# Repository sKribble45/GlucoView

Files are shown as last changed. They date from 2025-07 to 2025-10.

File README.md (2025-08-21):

# GlucoView
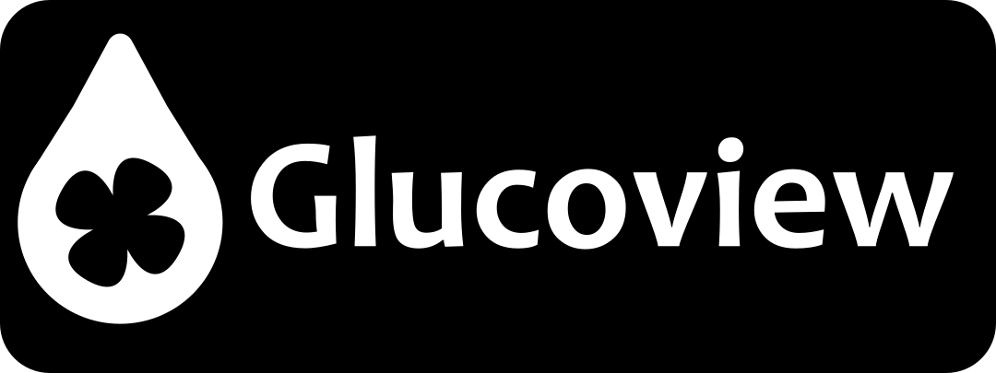
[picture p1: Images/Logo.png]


GlucoView is a low power, wall mounted E-paper display made for type one diabetics, used for checking blood sugar levels at a glance.

### <b style="color:red">WARNING: I am not a medical profesional, do not use this device for treatment decisions. Use ar your own risk.</b>

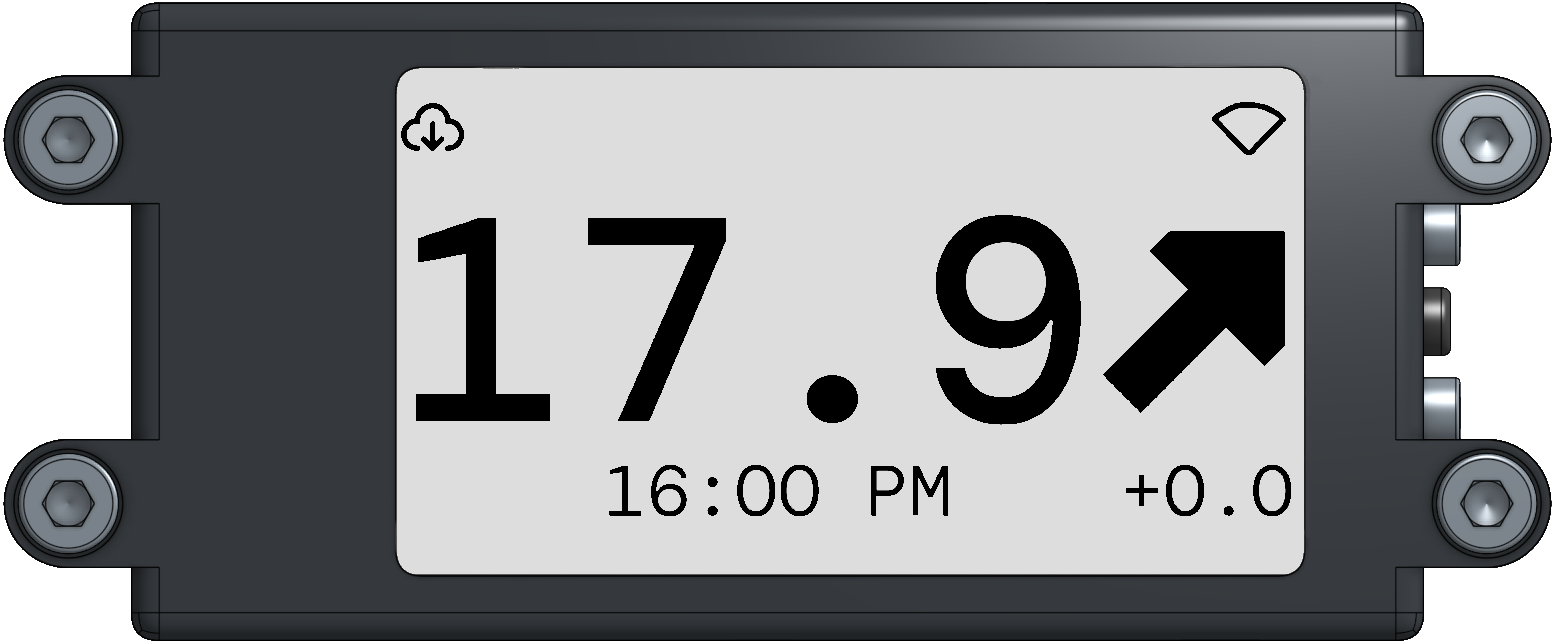
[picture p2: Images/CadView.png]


## Features:
- Uses a web UI and QR codes to make it simple and easy to configure using a smart device.
- Has options for dexcom share or nightscout data sources.
- Displays delta of glucose level on screen to make it easier to judge the rate of change.
- Uses an epaper screen and deep sleep which allows it to be extremely low power.
- Uses partial updates on the screen so glucose updates display extremely quick.
- Has OTA (Over the air) updates so you never have to manualy update.
- Mg/dl or Mmol/l option.

## Future plans
- List wifi networks rather than enter ssid manualy.
- Multiple Ui options including a graph.
- Battery powered version.
- Custom PCB.

## Configuration:
It uses a web ui to configure the wifi and dexcom credentials aswell as other settings. It is accesed by pressing the pairing button on the side of the device and scanning 2 Qr codes (One for the access point and one for the web page).

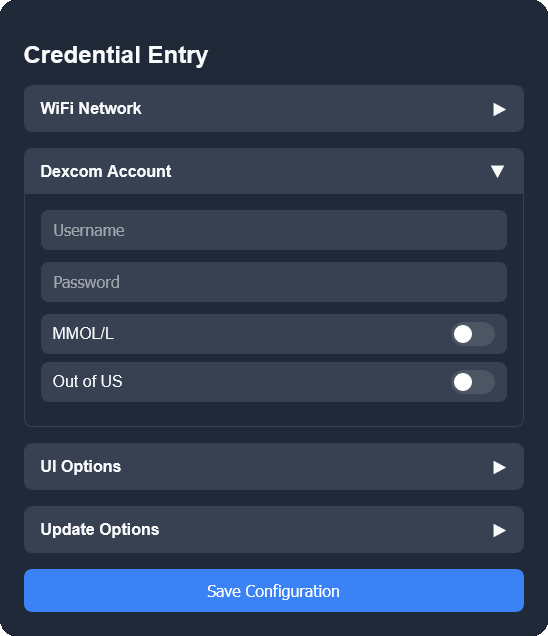
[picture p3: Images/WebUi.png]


# Build Your Own

## Cad Models:
Build Status (https://cad.onshape.com/documents/657beeeeb3e29ae5b1578280/w/7df4418e981bbd9b2a29f8d4/e/0c90e781795b9ee73095e2fe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)

[Stl Files](./Models)

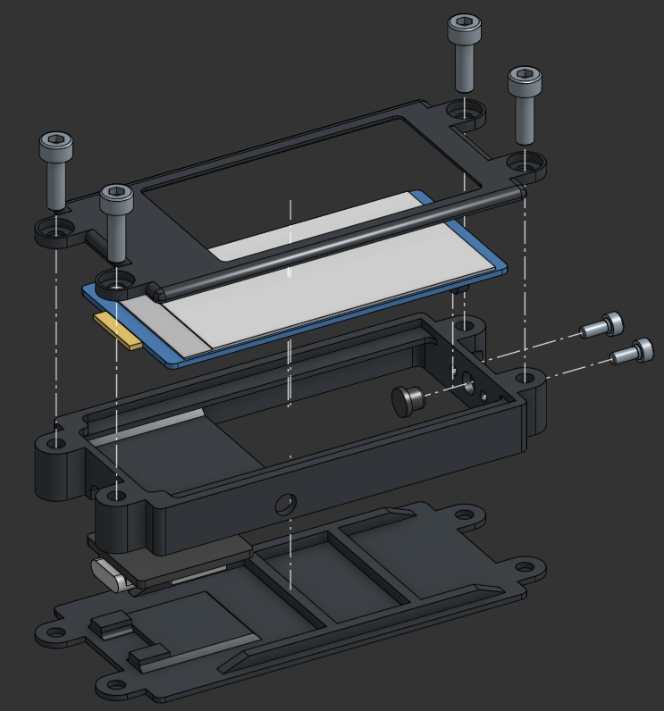
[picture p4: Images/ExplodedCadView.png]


## Parts:
- Esp32 S3 microcontroler from [Seeed Studio](https://www.seeedstudio.com/Seeed-Studio-XIAO-ESP32S3-Plus-p-6361.html) (Specificialy the Seed Studio XIAO ESP32-S3 Plus)
- 2.13 inch E-Paper display from [Waveshare](https://www.waveshare.com/pico-epaper-2.13.htm) (headers need to be de-soldered)
- [Push button](https://www.amazon.co.uk/B0BQ3CKVMT) (6mm x 6mm x 4.5mm)
- [Wire](https://shop.pimoroni.com/products/wire-spool?variant=40461209162) (Any wire will do as long as it is decently thin)
- [M3 x 14mm Bolts](https://www.amazon.co.uk/dp/B01FL898DU)
- M2 x 10mm & M2 x 6mm Bolts & M2 Nuts([M2 screw set](https://www.amazon.co.uk/Screws-Washers-Assortment-Socket-Printer/dp/B0CPHM3RC1))

## Tools required:
- Soldering iron, I recommend the [Pine 64 Pinecil](https://pine64.com/product/pinecil-smart-mini-portable-soldering-iron/).
- [Solder](https://www.amazon.co.uk/B08YRJJCV5) (Any will do, though i would reccomend lead free)
- [Wire cutters](https://shop.pimoroni.com/products/engineer-plastic-nippers?variant=41686138159187) (Any will do, these are just nice high quality ones)
- [Pliers](https://shop.pimoroni.com/products/miniature-needle-nose-pliers?variant=41151537250387) (Again any will do, these are just high quality)
- Alen keys / Screwdriver with alen bits.
- 3d printer or a service like [PCBway](https://www.pcbway.com/) or [jlcPCB](https://jlcpcb.com/)

## Pinout:
| Xiao ESP32 S3  | Device |
| --- | --- |
| D8 | EPD CLK |
| D10 | EPD DIN |
| D0 | EPD CS |
| D3 | EPD RST |
| D2 | EPD DC |
| D4 | EPD BUSY |
| D5 | BUTTON |

## Wiring Diagram:
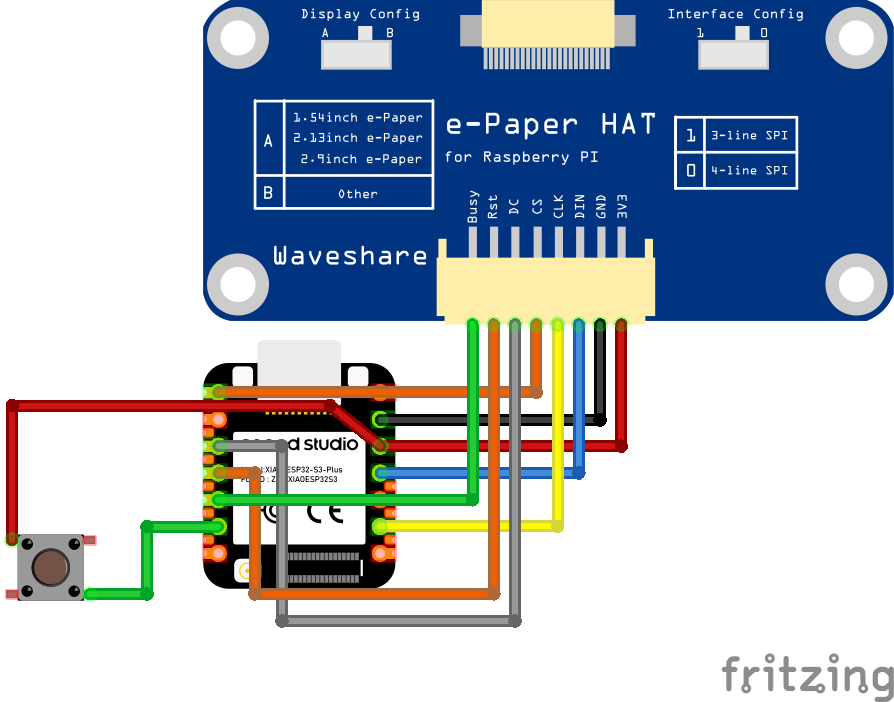
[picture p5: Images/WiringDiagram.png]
Wiring Diagram


### Guide comming soon :)

## Font License

This project uses a modified version of the DM Mono font, originally by Colophon Foundry.

The font has been renamed and modified to comply with the [SIL Open Font License 1.1](https://scripts.sil.org/OFL).  
See [FONT_LICENSES](./FONT_LICENSE.md) for full details.

## Credits:
- QR Code Libary by [Richard Moore](https://github.com/ricmoo/QRCode?tab=readme-ov-file)

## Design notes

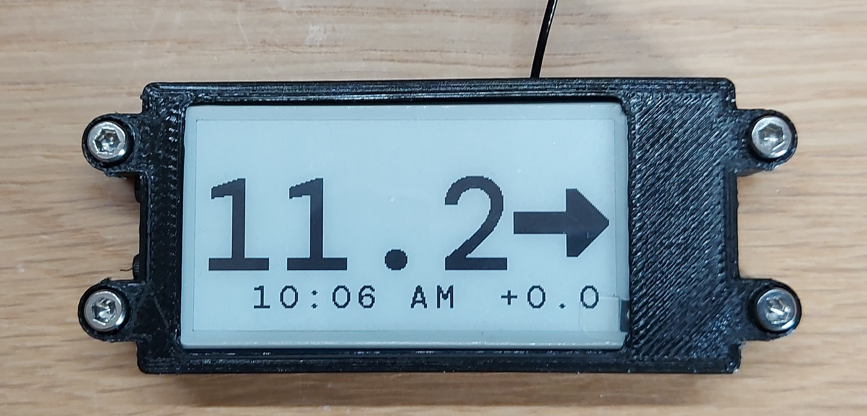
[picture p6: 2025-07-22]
Images/MainScreen.jpg

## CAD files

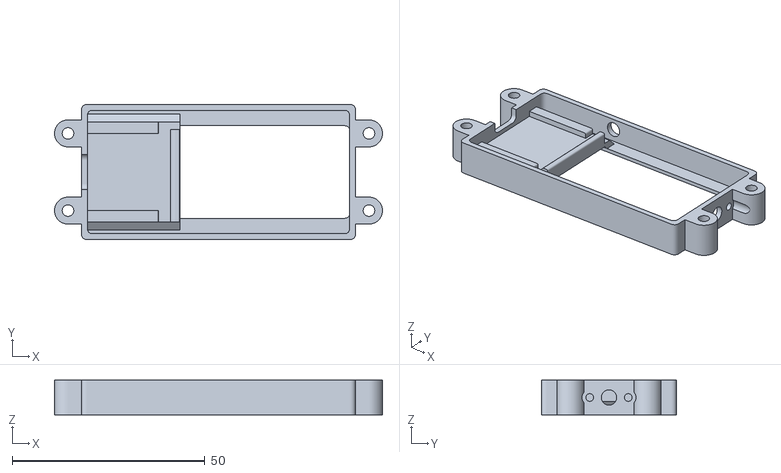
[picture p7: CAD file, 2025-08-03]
Models/Main Body.stl
85.0 x 35.0 x 9.00

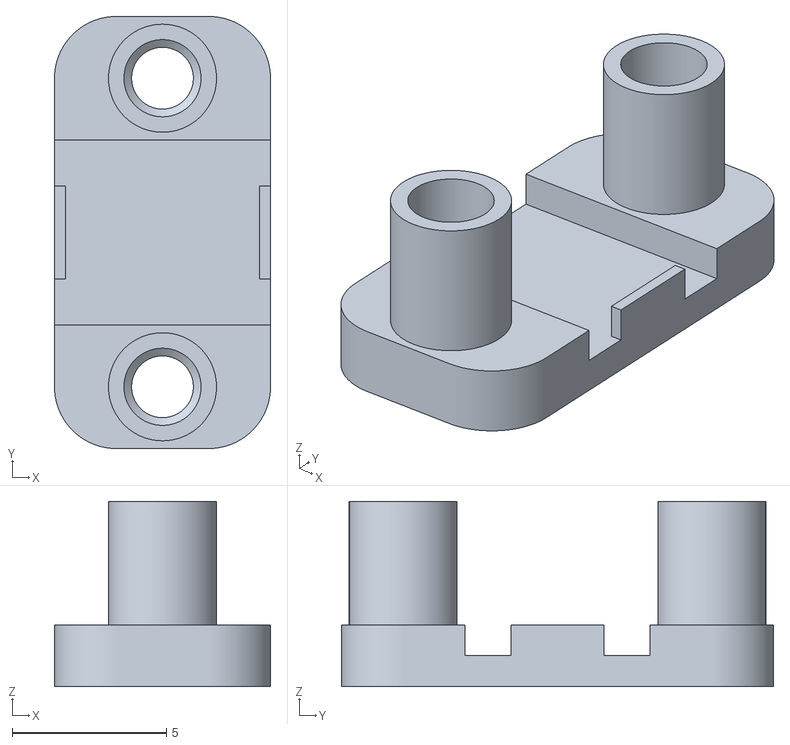
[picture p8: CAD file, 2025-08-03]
Models/Button Bracket.stl
7.00 x 14.0 x 6.00

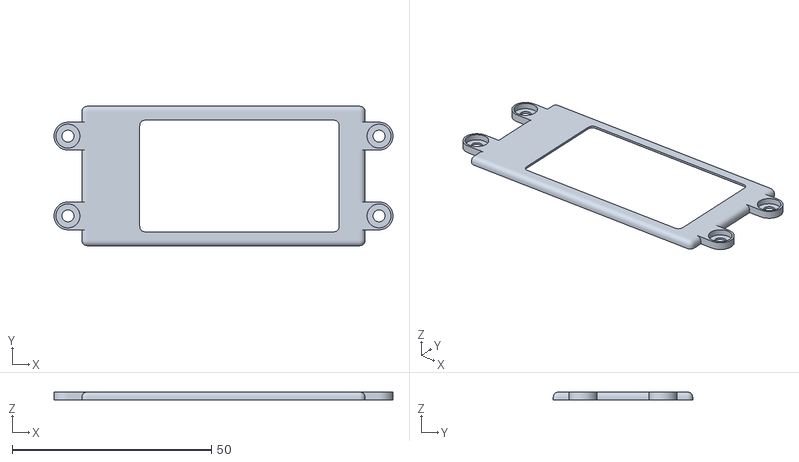
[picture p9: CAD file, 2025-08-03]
Models/Screen Besel.stl
85.0 x 35.0 x 2.00

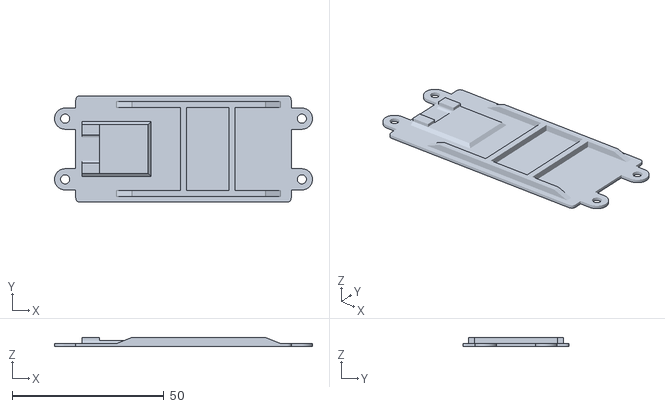
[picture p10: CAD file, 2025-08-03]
Models/Back Plait.stl
85.0 x 35.0 x 3.00

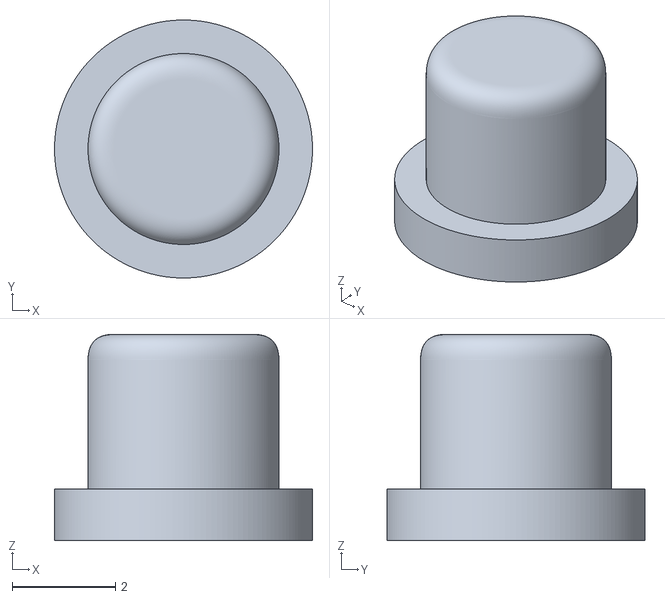
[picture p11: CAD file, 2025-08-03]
Models/Button.stl
5.00 x 5.00 x 4.00

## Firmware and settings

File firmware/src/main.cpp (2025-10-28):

#include <WiFi.h>
#include <Arduino.h>
#include <WiFiUdp.h>
#include <stdlib.h>
#include "UI.h"
#include "config/config_manager.h"
#include "wifi_manager.h"
#include "driver/rtc_io.h"
#include <nvs_flash.h>
#include "images/arrows.h"
#include "glucose_screen.h"
#include "update_manager.h"
#include "epoch_time.h"
#include "sleep.h"
#include "glucose/bg_datasource.h"
#include "config/config_ap.h"
using namespace std;

esp_sleep_wakeup_cause_t wakeup_reason;
RTC_DATA_ATTR GlucoseReading prevGl;

time_t rtcTime;

// Sleep times.
const int NO_TIME_SLEEP = 5;
const int NO_DATA_SLEEP = 5*60;
const int RETRY_NO_DATA_SLEEP = 15;
const int RETRY_TIMOUT_WIFI_SLEEP = 10;
const int WIFI_TIMEOUT_SLEEP = 30;
const int NO_WIFI_SLEEP = 5*60;
const int RETRY_NO_WIFI_SLEEP = 20;
const int DS_ERROR_SLEEP = 20;

const int SLEEP_TIME_DELAY = 4;

enum State{
    STATE_NORMAL,
    STATE_NO_DATA,
    STATE_NO_DATA_RETRY,
    STATE_NO_WIFI,
    STATE_WIFI_TIMEOUT,
    STATE_INCORRECT_WIFI,
    STATE_DS_ERROR
};

RTC_DATA_ATTR enum State state = STATE_NORMAL;

void RelTimestampSleep(int timeUntilNewReading){
    // Work out how long to sleep.
    int sleepTimeRemainder = timeUntilNewReading - (round(timeUntilNewReading/60)*60);
    if (sleepTimeRemainder == timeUntilNewReading){
        Sleep(sleepTimeRemainder + SLEEP_TIME_DELAY);
    }
    
    if (sleepTimeRemainder > 0){
        Sleep(sleepTimeRemainder);
    }
    else{
        Sleep(60);
    }
}

void NoData(unsigned long currentTime, Config config){
    if (state == STATE_NO_DATA_RETRY || state == STATE_NO_DATA){
        state = STATE_NO_DATA;
        Serial.println("No Data");
        DisplayError("No Data", true);

        int timeSniceLastReading = currentTime - prevGl.timestamp;
        int timeUntilNextReadingCheck = (5*60) - timeSniceLastReading - floor((timeSniceLastReading/60)/5)*5*60;
        if (!GetBooleanValue("rel-timestamp", config)){
            Sleep(timeUntilNextReadingCheck + SLEEP_TIME_DELAY);
        }
        else{
            RelTimestampSleep(timeUntilNextReadingCheck);
        }
    }
    else{
        state = STATE_NO_DATA_RETRY;
        Serial.println("No new reading yet.");
        Sleep(RETRY_NO_DATA_SLEEP);
    }
}

bool ShouldUpdateBg(unsigned long rtcTime){
    bool updateBg;
    int minsSinceLastReading = round((rtcTime - prevGl.timestamp)/60);
    updateBg = (
        // If it is 5m after the last reading.
        (state == STATE_NORMAL && (rtcTime - prevGl.timestamp > 5*60 - SLEEP_TIME_DELAY)) || 
        // Check if its a multiple of 5 if the state is No Data.
        (state == STATE_NO_DATA && minsSinceLastReading%5 == 0) ||
        (state == STATE_NO_DATA_RETRY)
    );
    return updateBg;
}

void UpdateDisplayGlucose(Config config){
    // Get the current epoch time.
    unsigned long currentTime = rtcTime;

    // Get the blood glucose reading from dexcom.
    GlucoseReading gl = prevGl;
    currentTime = GetEpoch();
    Serial.print("Epoch: ");
    Serial.println(currentTime);
    // Check if ntp time worked
    if (currentTime == 0){
        // If the ntp time dosnt work use inbuilt rtc if it has been set
        if (rtcTime > 10){
            Serial.println("Timeclient not updating, using built in rtc time.");
            currentTime = rtcTime;
        }
        else{
            // Reset as the rtc has not been set to the time via wifi.
            Serial.println("No previous time data.");
            Sleep(NO_TIME_SLEEP);
        }
    }
    if (GetGl()){
        gl = GlNow();
    }
    else{
        Serial.println("DS Error");
        DisplayError("DS Error", true);
        Sleep(DS_ERROR_SLEEP);
    }
    
    PrintGlucose(gl);
    prevGl = gl;
    
    // Update checking
    bool updateNeeded = CheckForUpdate();
    Serial.print("Update Needed: ");
    Serial.println(updateNeeded);
    if (GetBooleanValue("update-check", config)){
        UpdateGsNeedUpdate(updateNeeded);
    }
    if (GetBooleanValue("auto-update", config) && updateNeeded){
        OtaUpdate();
    }

    // No longer need wifi so turn it off to save some power.
    WiFi.disconnect(true);
    WiFi.mode(WIFI_OFF);

    // SLEEP!
    
    int timeUntilNewReading = (5 * 60) - (currentTime - gl.timestamp);

    // sleep for the next reading.
    if(timeUntilNewReading < 0){
        gl.minsSinceReading = round((currentTime - gl.timestamp) / 60);
        DisplayGlucose(gl);

        NoData(currentTime, config);
    }
    else {
        PrintGlucose(gl);
        DisplayGlucose(gl);
        
        state = STATE_NORMAL;
        if (GetBooleanValue("rel-timestamp", config)){
            RelTimestampSleep(timeUntilNewReading);
        }
        else{
            Sleep(timeUntilNewReading + SLEEP_TIME_DELAY);
        }
    }
}

void UpdateDisplay(){
    prevGl.minsSinceReading = round((rtcTime - prevGl.timestamp) / 60);
    
    PrintGlucose(prevGl);
    if (state == STATE_NO_DATA){
        DisplayError("No Data", true, prevGl);
    }
    else{
        DisplayGlucose(prevGl);
    }
    
    int timeUntilNewReading = (5 * 60) - (rtcTime - prevGl.timestamp);

    RelTimestampSleep(timeUntilNewReading);
}

void OnStart(Config config) {
    String wifiSsid = GetStringValue("wifi-ssid", config);
    String wifiPassword = GetStringValue("wifi-password", config);
    #if DEBUG
        Serial.print("ssid: ");
        Serial.print(wifiSsid);
        Serial.print(" , password: ");
        Serial.println(wifiPassword);
    #endif
    
    time(&rtcTime);
    Serial.print("RTC time: ");
    Serial.println(rtcTime);

    if (ShouldUpdateBg(rtcTime) || prevGl.bg == 0.0 || rtcTime <= 10){
        int networkConnectionCode = ConnectToNetwork(wifiSsid, wifiPassword);
        if (networkConnectionCode == 0){
            UpdateGsSignalStrength(GetWifiSignalStrength());
            UpdateDisplayGlucose(config);
        }
        else{
            UpdateGsSignalStrength(0);
            bool savedNetworkExists = SavedNetworkExists(wifiSsid);
            if (savedNetworkExists){
                if (networkConnectionCode == 6){
                    Serial.println("Failed to connect to wifi network (Incorrect Password) :(");
                    if (state != STATE_INCORRECT_WIFI){
                        state = STATE_INCORRECT_WIFI;
                        Sleep(WIFI_TIMEOUT_SLEEP);
                    }
                    else{
                        DisplayError("WiFi Fail", true);
                        Sleep(NO_WIFI_SLEEP);
                    }
                }
                else{
                    Serial.println("Failed to connect to wifi network (Timed out) :(");
                    if (state != STATE_WIFI_TIMEOUT){
                        state = STATE_WIFI_TIMEOUT;
                    }
                    Sleep(WIFI_TIMEOUT_SLEEP);
                    
                    //TODO: Handle Error
                }
            }
            else{
                Serial.println("Failed to connect to wifi network (Not found) :(");
                state = STATE_NO_WIFI;
                Sleep(NO_WIFI_SLEEP);
                //TODO: Handle Error
            }
        }
    }
    else{
        Serial.println("Updating Mins since reading.");
        UpdateDisplay();
    }
}

void StartConfiguration(Config &config){
    String ApPassword = "glucoview_"+GetSerialNumber();
    String ApSsid = "GlucoView" + GetSerialNumber();
    HostConfigAP(config, ApSsid.c_str(), ApPassword.c_str());
    SaveConfig(config);

    UiFullClear();
    UiSetupFinish();
    UiShow();
    while (!digitalRead(BUTTON_PIN)){delay(50);}
    while (digitalRead(BUTTON_PIN)){delay(50);}
    ESP.restart();
}

void setup(){
    Serial.begin(115200);
    // Get the reason it was woken from sleep.
    wakeup_reason = esp_sleep_get_wakeup_cause();
    // Pull down the button pin to ground so it can see a change when shorted to 3.3v
    pinMode(BUTTON_PIN, INPUT_PULLDOWN);
    int buttonValue = digitalRead(BUTTON_PIN);

    Serial.println("Initialise display");
    DispInit();
    Serial.println("Display initilised.");

    // If it hasnt woken up from sleep because of the button press (so not pairing) and the button is down (when it is plugged )
    if (wakeup_reason != ESP_SLEEP_WAKEUP_EXT0 && buttonValue) {UpdateMode();}

    //!! DO NOT REMOVE CODE BEFORE THIS MESSAGE UNLESS YOU KNOW WHAT YOU ARE DOING (you may need to take appart the device to bootstrap so that you can re-program if you do)

    // Delay to connect to serial port.
    #if DEBUG
        delay(2000);
    #endif

    Config config;
    LoadConfig(config);
    #if DEBUG
        PrintConfigValues(config);
    #endif
    // Load config to other components.
    UpdateUiConfig(config);
    UpdateUpdateManagerConfig(config);
    UpdateDataSourceConfig(config);

    // Setup screen when you start the device for the first time.
    if (!SerialNumberExists() || !ConfigExists(config)){
        UiSetupScreen();
        UiShow();
        while (!digitalRead(BUTTON_PIN)){delay(50);}
        RandomiseSerialNumber();
        delay(50);
        StartConfiguration(config);
    }

    // If it was woken up by the button press (or config dosnt exist) enter configuration mode.
    if (wakeup_reason == ESP_SLEEP_WAKEUP_EXT0){
        Serial.println("Entering Configuration");
        StartConfiguration(config);
        // Restart the device after configuration.
        ESP.restart();
    }

    // Run the main start code
    OnStart(config);
}


void loop(){
    // :)
}

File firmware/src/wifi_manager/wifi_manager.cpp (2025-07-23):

#include <WiFi.h>
#include <WiFiUdp.h>
#include <list>
#include "wifi_manager.h"
#include <Arduino.h>
#include <unordered_map>
using namespace std;
const int WIFI_TIMEOUT = 15;

bool SavedNetworkExists(WifiNetwork network){
    WiFi.disconnect();
    // Scan for networks.
    Serial.println("Scanning for networks...");
    int foundNetworks = WiFi.scanNetworks();
    Serial.println("Finished scanning.");
    // if there are no networks found display no wifi and sleep.
    if (foundNetworks == 0){
        Serial.println("No wifi networks found :(");
        return false;
    }

    Serial.println("Networks Found:");
    for (int scannedNetworkIndex = 0; scannedNetworkIndex < foundNetworks; scannedNetworkIndex++){
        String scanned_network_ssid = WiFi.SSID(scannedNetworkIndex); // get the ssid from the index of a network that has has been scanned
        Serial.print(" -");
        Serial.println(scanned_network_ssid);


        // if the ssid from one of the saved networks equals one of the scanned networks then 
        if (network.ssid == scanned_network_ssid){
            Serial.print("Found saved network: ");
            Serial.println(network.ssid);
            return true;
        }
        
    }
    return false;
}

WifiNetwork GetSavedNetwork(list<WifiNetwork> saved_networks){
    WiFi.disconnect();
    // Scan for networks.
    Serial.println("Scanning for networks...");
    int foundNetworks = WiFi.scanNetworks();
    Serial.println("Finished scanning.");
    // if there are no networks found display no wifi and sleep.
    if (foundNetworks == 0){
        Serial.println("No wifi networks found :(");
        return {"",""};
    }

    bool savedNetworkExists = false;
    WifiNetwork network = {"", ""};


    Serial.println("Networks Found:");
    for (int scannedNetworkIndex = 0; scannedNetworkIndex < foundNetworks; scannedNetworkIndex++){
        String scanned_network_ssid = WiFi.SSID(scannedNetworkIndex); // get the ssid from the index of a network that has has been scanned
        
        Serial.print(" -");
        Serial.print(scanned_network_ssid);
        Serial.print(" ");
        Serial.println(WiFi.RSSI(scannedNetworkIndex));

        for (WifiNetwork saved_network : saved_networks){
            // nicer variable names cuz i feel like it.
            String ssid = saved_network.ssid;
            String pass = saved_network.password;
            // if the ssid from one of the saved networks equals one of the scanned networks then return it.
            if (ssid == scanned_network_ssid){
                savedNetworkExists = true;
                network.ssid = scanned_network_ssid;
                network.password = pass;
                break;
            }
        }
        if (savedNetworkExists){
            Serial.print("Found saved network: ");
            Serial.println(network.ssid);
            break;
        }
    }
    WiFi.scanDelete();
    return network;
    
}

bool ConnectToNetwork(String ssid, String password){
    
    // connect to the found wifi network.
    // set wifi mode to station.
    WiFi.mode(WIFI_STA); 
    // disconnect from any existing network. (shouldent be neccicary)
    WiFi.disconnect(); 
    delay(500);
    // connect to a new network.
    WiFi.begin(ssid, password);

    
    int waitProgress = 0;
    Serial.print("Attempting to connect to ");
    Serial.println(ssid);

    Serial.println("Status [6: DISCONNECTED, 5: CONNECTION_LOST, 4: CONNECT_FAILED, 3: WL_CONNECTED, 2: SCAN_COMPLETED, 1: NO_SSID_AVAIL, 0: IDLE]: ");
    while (WiFi.status() != WL_CONNECTED && waitProgress <= (WIFI_TIMEOUT * 2)){
        Serial.print(WiFi.status());
        delay(500);
        waitProgress ++;
    }
    Serial.println();

    if (WiFi.status() == WL_CONNECTED){
        Serial.print("Success! connected to ");
        Serial.println(ssid);
        return true;
    }
    else{
        Serial.println("Failed to conect to network. :(");
        return false;
    }
}


int GetSignalStrength(){
    int8_t wifiRSSI = WiFi.RSSI();
    if (wifiRSSI < -80){return 0;}
    else if (wifiRSSI < -70) {return 1;}
    else if (wifiRSSI < -60) {return 2;}
    else if (wifiRSSI < -30) {return 3;}
    else {return 0;}
}

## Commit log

2025-07-02 Switched the pins of the button and screen rst to make the button enter programming mode.
2025-07-05 Added a update mode to aid flashing the device
2025-07-05 Fixed Update Mode, removed unnecicary serial prints
    [main.cpp, wifi_manager.cpp]
2025-07-06 Updated to Arduino-ESP32 3.2.1
2025-07-22 Fixed arrow not showwing correctly.
    [UI.cpp]
2025-07-23 Addid Pinout and wiring diagram
2025-07-23 Updated wiring diagram
2025-08-03 Added LICENSE and other files.
    [Back Plait.stl, Button Bracket.stl, Button.stl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]
2025-08-04 Fixed not connecting to wifi network.
    [config_manager.cpp, main.cpp]
2025-08-10 Moved pin defenitions to build flags.
2025-08-13 Fixed not updating when using relative timestamp.
    [main.cpp]
2025-08-14 Fixed no data screen when using relative timestamp.
    [main.cpp]
2025-08-16 Fixed wifi signal strength icon showing 0 when using relative timestamp.
    [main.cpp]
2025-08-21 Fixed nigthscout not getting timestamp.
    [datasource_nightscout.cpp]
2025-08-25 Fixed Trend and No Data lingering also replaced wakeup time with RTC.
    [UI.cpp, bg_datasource.cpp, datasource_dexcom.cpp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]
2025-08-26 Fixed update checking, disabled debug mode.
    [update_manager.cpp]
2025-10-28 Fixed missing readings when in NoData state.
    [main.cpp]
2025-10-28 Fixed some checkboxes not loading their state in the config gui.
    [update_manager.cpp]
